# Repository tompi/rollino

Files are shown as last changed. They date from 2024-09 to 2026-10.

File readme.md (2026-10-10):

Rollino
=======

An attempt to make a cheap, solid and low profile DIY finger trackball.

The ball floats just 1 mm above the table on three ceramic support balls.
Two PMW3610 sensors look up at the ball from below its equator, placed so
their lines of sight are orthogonal (X, Y and twist are all observable).
A Seeed XIAO nRF52840 running ZMK and a 602020 LiPo lie flat in a squashed
dome in front of the ball. The XIAO is soldered upside down onto a base PCB
that sits in a groove in the underside and reaches round under both sensors,
each wired up with a short FPC ribbon; a cover over the whole underside hides
it, held by the same screws.

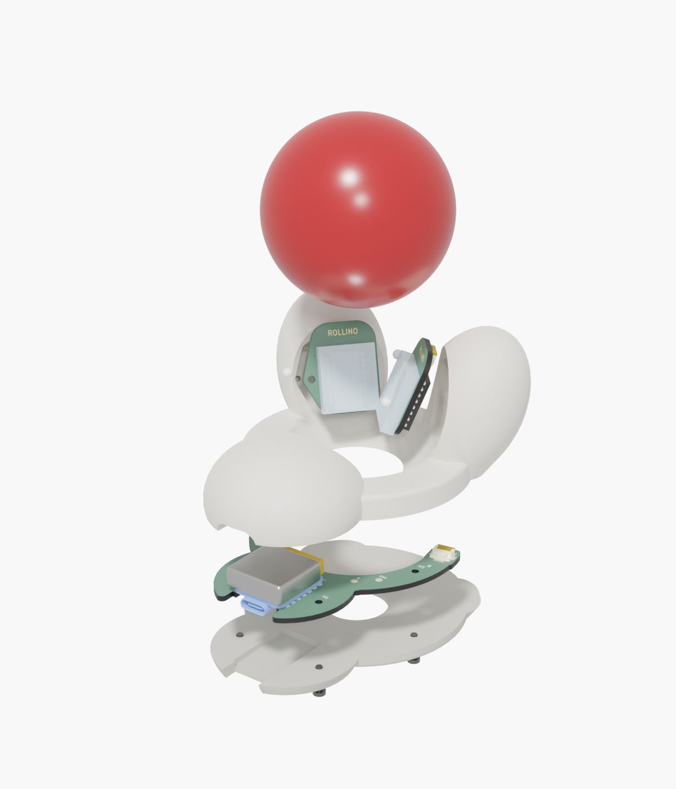
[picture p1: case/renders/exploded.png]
Exploded view


- `case/rollino.scad` - parametric OpenSCAD model (ball size, sensor/MCU
  placement, battery, ...). Set `part` to `assembly`, `exploded`, `hardware`, `section`,
  or `body` / `base_cover` for printable parts.
- `case/renders/` - preview renders: `case/render_previews.sh` (OpenSCAD) and
  `case/render_exploded.sh` (Blender, with KiCad's 3D models of the boards).
- `pcb/` - KiCad projects for the sensor boards and the base board: schematics
  and routed boards, generated from the case model (see [pcb/readme.md](pcb/readme.md)).

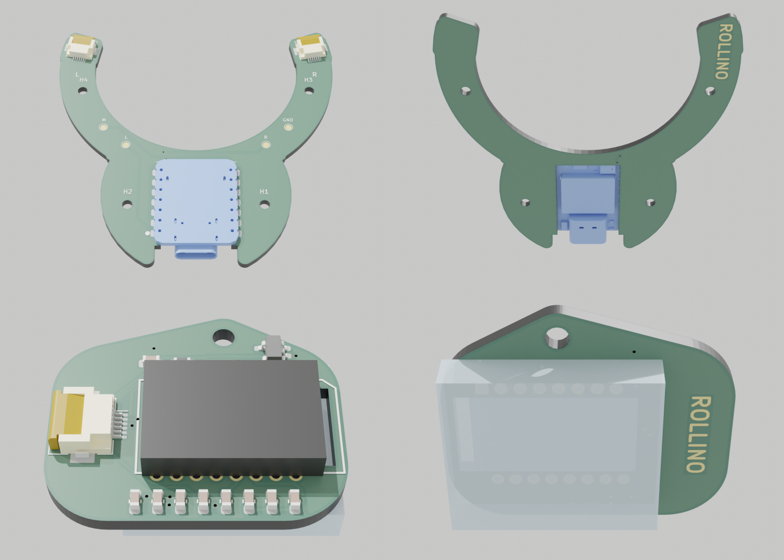
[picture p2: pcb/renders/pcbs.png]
The PCBs, top and bottom

- [parts.md](parts.md) - everything to order for one Rollino.
- `datasheets/` - component datasheets. The PMW3610 datasheet is available
  [here](https://www.epsglobal.com/Media-Library/EPSGlobal/Products/files/pixart/PMW3610DM-SUDU.pdf?ext=.pdf).

Firmware
--------

ZMK, built by GitHub Actions on every push (download `firmware.zip` from the
run, then double-tap the XIAO's reset and copy the `.uf2` onto it). It's a
standalone Bluetooth/USB mouse.

- `zmk/boards/shields/rollino/` - the shield: pins, the two PMW3610 sensors
  (Zephyr's driver), three optional buttons.
- `zmk/src/ball_fusion.c` - combines the two sensors: each one only sees the
  ball's surface sliding past in its own tilted plane; together they give the
  ball's whole rotation. Rolling moves the pointer (as if the finger on top
  dragged it), twisting about the vertical axis scrolls.
- `config/rollino.keymap` - the buttons: left, right, middle click.

| XIAO pin | Use |
|---|-----|
| D8 | SCLK, both sensors |
| D10 | SDIO, both sensors (SPI MOSI and MISO on the same pin) |
| D7 | NCS, right sensor |
| D6 | NCS, left sensor |
| D3 | MOTION, right sensor |
| D2 | MOTION, left sensor |
| D0, D1, D9 | optional buttons to GND: left, right, middle click |
| D4, D5 | free |

**Calibrating the sensors' orientation.** The fusion needs to know which way
each sensor's X axis points (`rotation` in the shield's `ball_fusion` node,
plus the sensor's `invert-x` / `invert-y`), which depends on how the chip
sits on the sensor PCB. Roll the ball right: the pointer should go right;
towards you: down; twist it: scroll, with no drift. If one direction is off,
try one sensor at a time (cover the other's lens) and fix its rotation /
inversion until rolling right moves the pointer mostly right.

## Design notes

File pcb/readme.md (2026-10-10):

Rollino PCBs
============

Two KiCad 8 projects, generated from the case model: board outlines, and
where the XIAO, the FPC connectors and the screw holes go, all come from
`case/rollino.scad`.

Both boards, top and bottom

Rebuild them after changing the case (KiCad's own Python; Freerouting 1.5,
Java, Blender 3.x and ImageMagick for routing and rendering):

```
PY=/Applications/KiCad/KiCad.app/Contents/Frameworks/Python.framework/Versions/Current/bin/python3
$PY pcb/gen/generate.py     # schematics, footprints placed on their nets
$PY pcb/gen/route.py        # Freerouting routes every net, GND poured on both layers
pcb/gen/render_pcbs.sh      # the renders above, the layout images and schematic PDFs
```

They overwrite the projects, so make changes in the scripts rather than the
KiCad files, or stop using them once you start editing the boards by hand.

Both boards are routed (0.2 mm tracks, 0.15 mm clearance, 0.3 mm from the
edges, 0.6/0.3 mm vias) and pass DRC with nothing to report, warnings
included (`kicad-cli pcb drc --schematic-parity --severity-all`); the
schematics pass ERC. The sensor board's references are on its fab layer
only, as are the base board's test points' (their labels name them): the
silkscreen has no room for them.

Sensor board (`sensor/`, two needed)
--------------------------------------

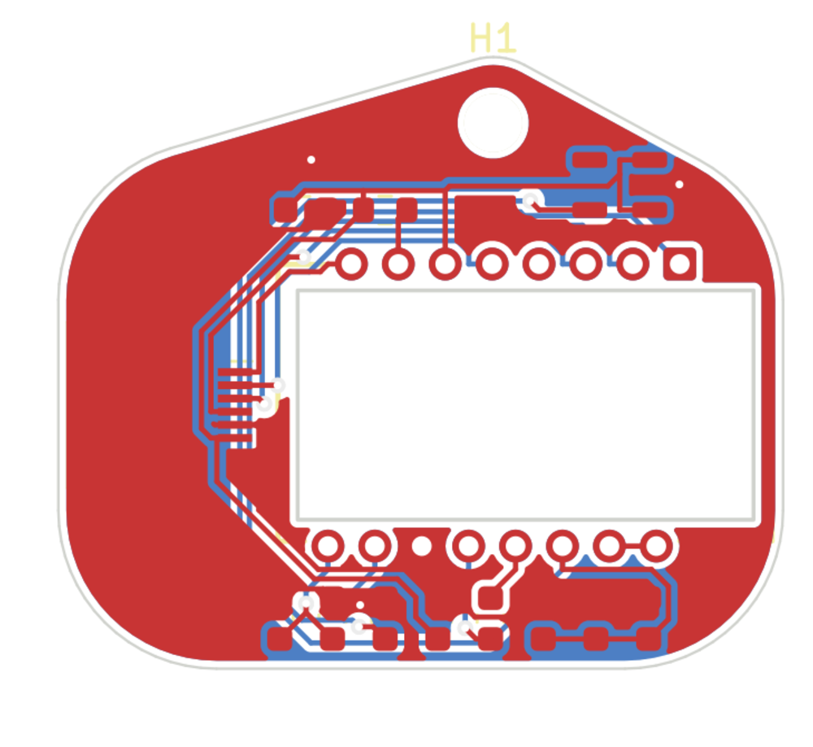
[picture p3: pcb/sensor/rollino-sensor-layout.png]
Sensor board


[Schematic (PDF)](sensor/rollino-sensor-schematic.pdf)

The same board for both sensors. It's screwed into its pod from the ball
side, chip side out, lens towards the ball; the case's pocket matches its
outline, ear included.

- PMW3610DM-SUDU + LM18-LSI lens: circuit and footprint (with the lens cutout)
  after [badjeff/pmw3610-pcb](https://github.com/badjeff/pmw3610-pcb)
  (CERN-OHL-P-2.0)
- TPS7A0518 1.8 V LDO for the sensor's core: 1 uA quiescent, instead of the
  ~34 uA of the TLV74318 used there, which would otherwise draw more than the
  resting sensor
- FH12-6S-0.5SH FPC connector at the board's up-slope end, mouth facing off
  the edge, so the ribbon is easy to push in and latch before the board goes
  into its pod; the ribbon then bends back over the connector and runs over
  the chip's back to the base board (the pod has room for the bend)
- the ribbon's way down through the pod is roomy (5.5 mm wide, the case
  checks it with a 1.5 mm thick stand-in: `part="fpc_check"` must be empty),
  so its free end can be fed through from the pod or from underneath before
  the boards go in
- the regulator's EN is tied to its VIN by a fixed track between its rows of
  pins (route.py keeps it): the board edge leaves no other way in
- a small ROLLINO logo in bare copper on the back, between the edge and the
  lens
- board frame: origin on the optical axis, x down the slope (towards the
  table), y sideways; nothing goes behind the ear (y beyond -7.9 mm, x
  -6.9..-0.9), where the case has the screw boss

Base board (`base/`)
--------------------

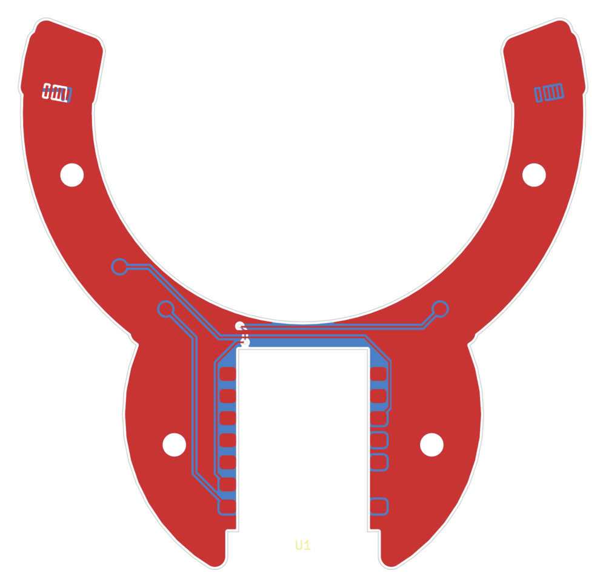
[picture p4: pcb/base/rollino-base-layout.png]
Base board


[Schematic (PDF)](base/rollino-base-schematic.pdf)

Lies in a groove in the case's underside, held (with the cover under it) by
four M2 screws.

- Seeed XIAO nRF52840 soldered **upside down** by its castellated edges: its
  parts (USB-C included) hang through the cutout into a pocket in the cover;
  its battery pads face up, and the LiPo's leads solder straight onto them
- J1 (right sensor) and J2 (left) at the band's ends, along it, mouths facing
  the ribbons coming along the channel in the case's underside
- TP1-TP3: optional buttons (left, middle, right click) to TP4 (GND)
- the ROLLINO logo is bare copper (no solder mask) on the back of the band
- pins as in the firmware (`zmk/boards/shields/rollino/rollino.overlay`)

Ribbons
-------

Two 6-way 0.5 mm FFCs, 50 mm long (the stock length: 40 mm ones are hard
to find), with opposite-side (type B) contacts. Each comes down from its
sensor pod under the band's old end, turns in, and with one crease (about
45 degrees, folded flat) lies along a channel in the case's underside,
straight into the base board's connector at the end of the band; the case
model sets where that is from the cable's length (`fpc_len`). The crease
turns the ribbon over, hence type B. The pins at each end are numbered from
the ribbon's path so that each signal meets itself: put the ribbon in, fold
it at the crease and lay it in its channel before the base board goes up.

Parts
-----

| Board | Ref | Part |
|---|-----|---|
| sensor (x2) | U1 | PMW3610DM-SUDU + LM18-LSI lens |
| | U2 | TPS7A0518PDBVR (SOT-23-5) |
| | J1 | Hirose FH12-6S-0.5SH (or JUSHUO AFC01-S06FCA) |
| | R1 | 10k 0603 |
| | C1 | 3.3 uF 0603 |
| | C2, C3 | 100 nF 0603 |
| | C4 | 100 nF X7R 0603 |
| | C5 | 10 nF 0603 |
| | C6 | 10 uF X7R 0603 |
| | C7 | 10 nF X7R 0603 |
| | C8, C9 | 1 uF 0603 |
| base | U1 | Seeed XIAO nRF52840 (not Sense) |
| | J1, J2 | Hirose FH12-6S-0.5SH (or JUSHUO AFC01-S06FCA) |

`lib/` has the project's own symbols, footprints and 3D models (the XIAO's
from Seeed's, the PMW3610 and its lens as plain blocks); everything else is
from KiCad's standard libraries.

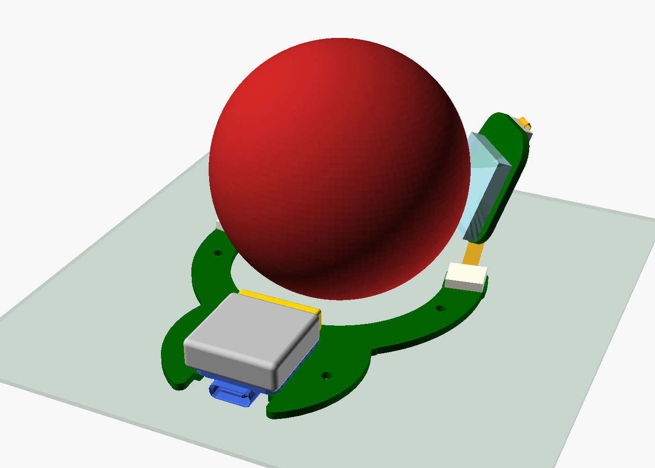
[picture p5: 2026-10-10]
case/renders/hardware_front.png

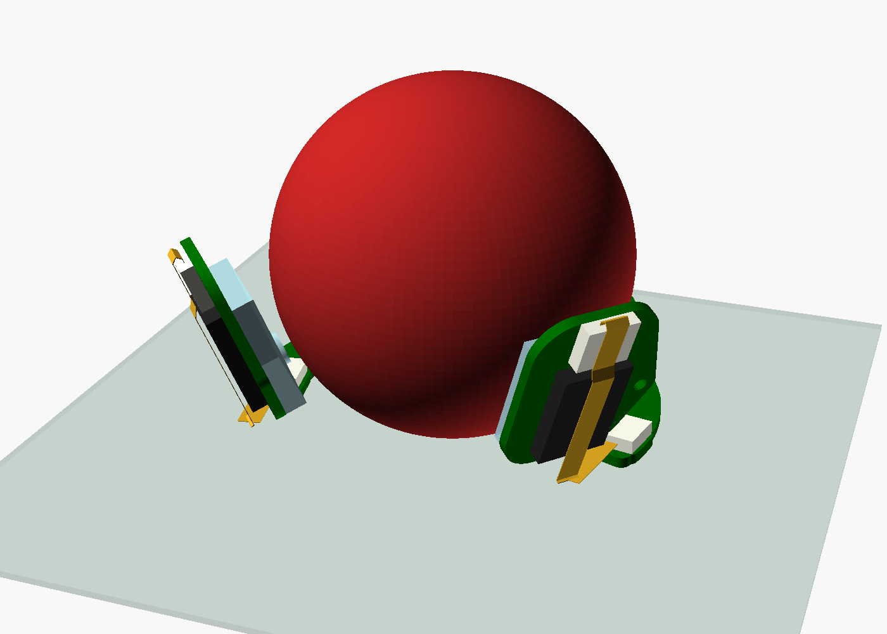
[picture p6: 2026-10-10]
case/renders/hardware_back.png

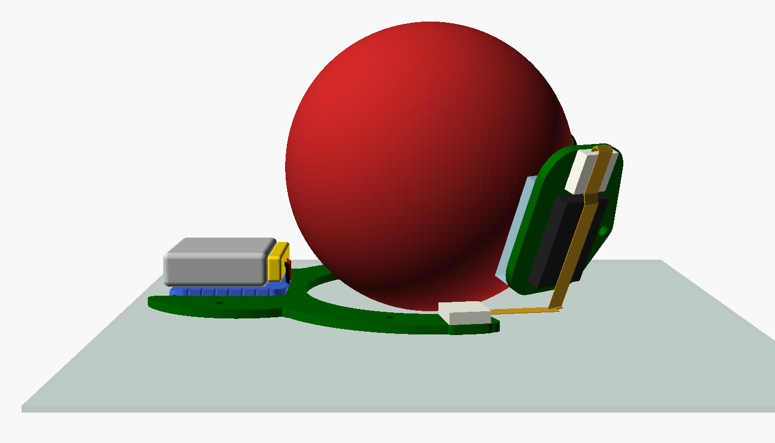
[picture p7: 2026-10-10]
case/renders/hardware_side.png

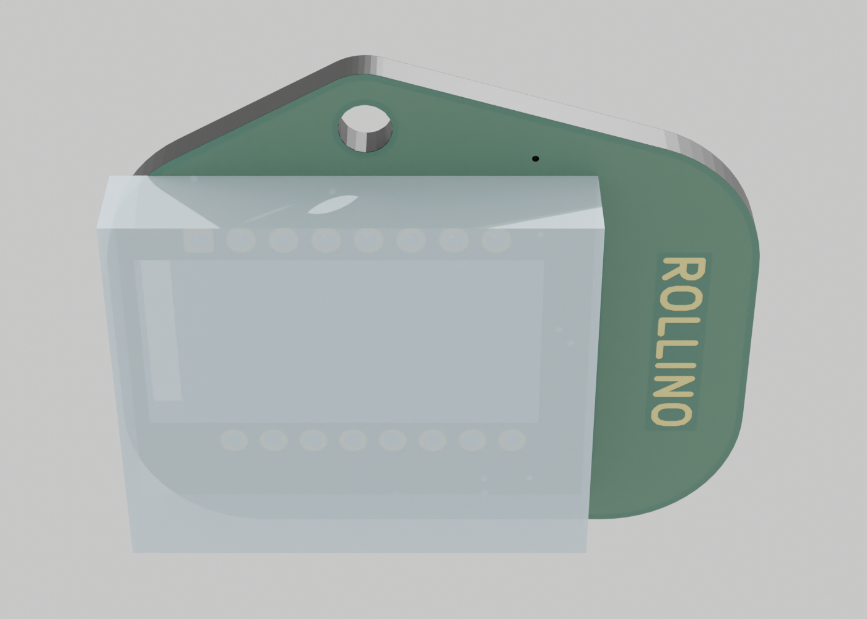
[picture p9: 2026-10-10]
pcb/renders/sensor-bottom.png

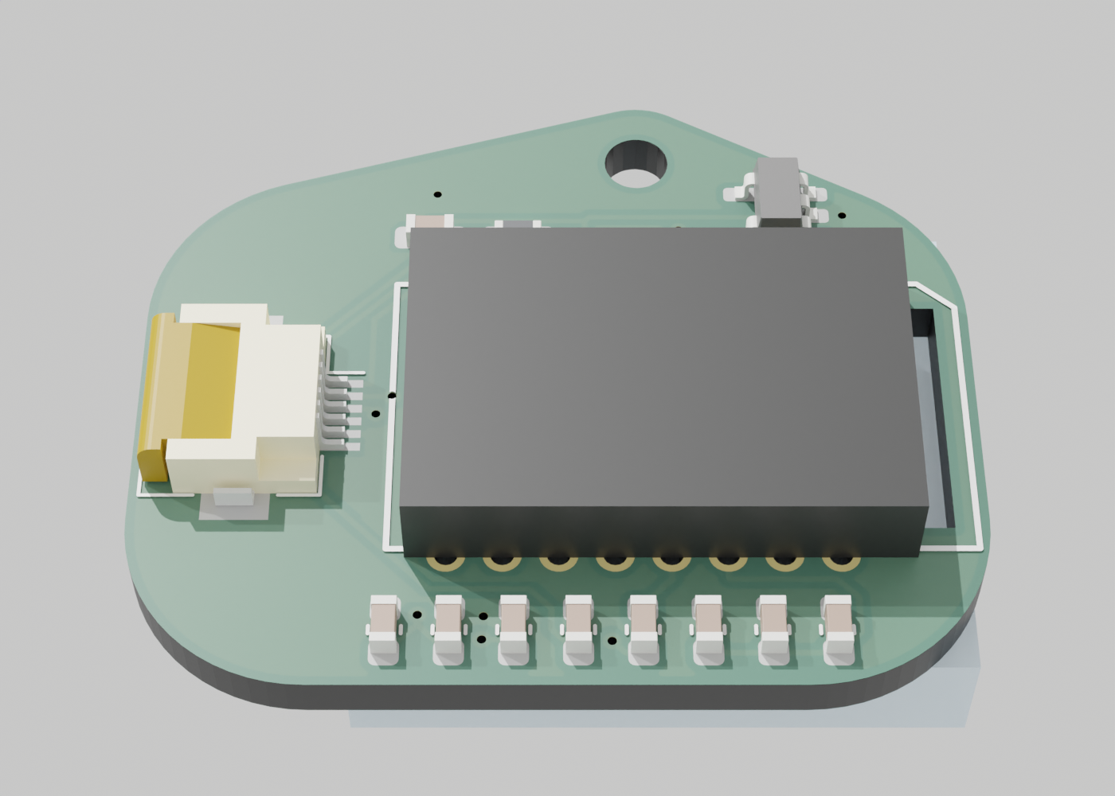
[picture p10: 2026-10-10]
pcb/renders/sensor-top.png

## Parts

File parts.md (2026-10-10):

Parts list
==========

Everything for one Rollino; quantities are totals (it has two sensor boards).
The case itself (`body` and `base_cover` in `case/rollino.scad`) is printed.

PCBs
----

| Qty | Board | Notes |
|-----|---|---|
| 2 | sensor board (`pcb/sensor/`) | 2 layers, 1.6 mm FR4; has a cutout for the lens |
| 1 | base board (`pcb/base/`) | 2 layers, 1.6 mm FR4; has a cutout for the XIAO's parts |

0.2 mm tracks, 0.15 mm clearance, 0.3 mm drills: any fab's standard process.
Both have a bare-copper logo, so pick ENIG (or HASL) rather than bare copper
finish.

Electronics
-----------

| Qty | Part | Where | Notes |
|-----|---|---|---|
| 1 | Seeed XIAO nRF52840 (not Sense) | base U1 | soldered upside down by its edge pads |
| 2 | PixArt PMW3610DM-SUDU | sensor U1 | |
| 2 | LM18-LSI lens | under each PMW3610 | the PMW3610's lens; often sold with it |
| 2 | TI TPS7A0518PDBVR (1.8 V LDO, SOT-23-5) | sensor U2 | |
| 4 | Hirose FH12-6S-0.5SH(55) (or JUSHUO AFC01-S06FCA) | sensor J1, base J1/J2 | 6-pin, 0.5 mm FPC connector |
| 2 | 6-way FFC, 0.5 mm pitch, 50 mm, **opposite-side (type B) contacts** | sensor to base | for 0.3 mm thick FPC connectors (FH12); 50 mm is the stock length |
| 1 | LiPo 602020, about 200 mAh, with protection board | on the XIAO's back | up to 22 x 20 x 6.5 mm; leads solder to the XIAO's battery pads |

Passives, all 0603, for both sensor boards together (10 V or more):

| Qty | Value | Where (on each sensor board) |
|-----|---|---|
| 6 | 100 nF X7R | C2, C3, C4 |
| 4 | 10 nF X7R | C5, C7 |
| 4 | 1 uF | C8, C9 |
| 2 | 3.3 uF | C1 |
| 2 | 10 uF X7R | C6 |
| 2 | 10 k resistor | R1 |

Optional: up to three momentary switches for left, middle and right click,
wired from the base board's TP1-TP3 pads to TP4 (GND).

Mechanical
----------

| Qty | Part | Notes |
|-----|---|---|
| 1 | 55 mm trackball ball | the size Kensington's trackballs use (Expert Mouse, SlimBlade), sold as replacements |
| 3 | 3 mm ceramic bearing balls (ZrO2 or Si3N4) | the ball's supports; get a few spares |
| 4 | M2 x 8 countersunk thread-forming screws for plastic | through the cover and base board into the case |
| 2 | M2 x 6 thread-forming screws for plastic, low (pan or wafer) head | one through each sensor board's ear |

Screw lengths are from the model: the cover and base board are 5.2 mm
together, with 4.5 mm pilot holes above them; each sensor board is 1.6 mm,
with a 5 mm pilot hole behind it.

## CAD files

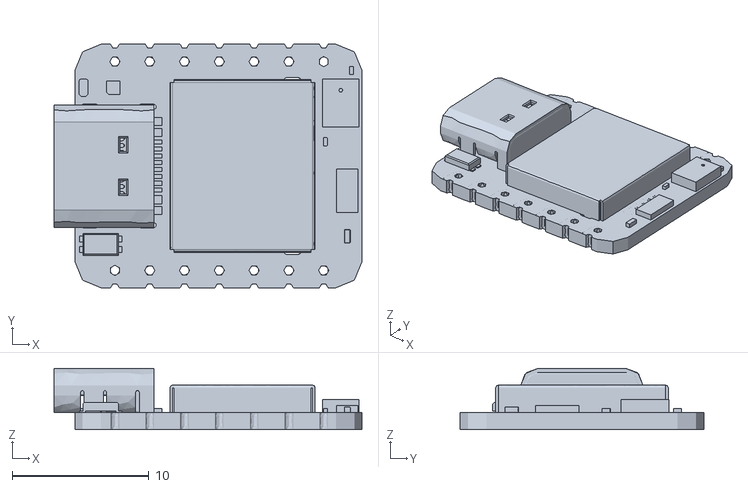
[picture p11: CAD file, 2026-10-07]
pcb/3d/xiao-nrf52840.stl
22.5 x 17.8 x 4.46

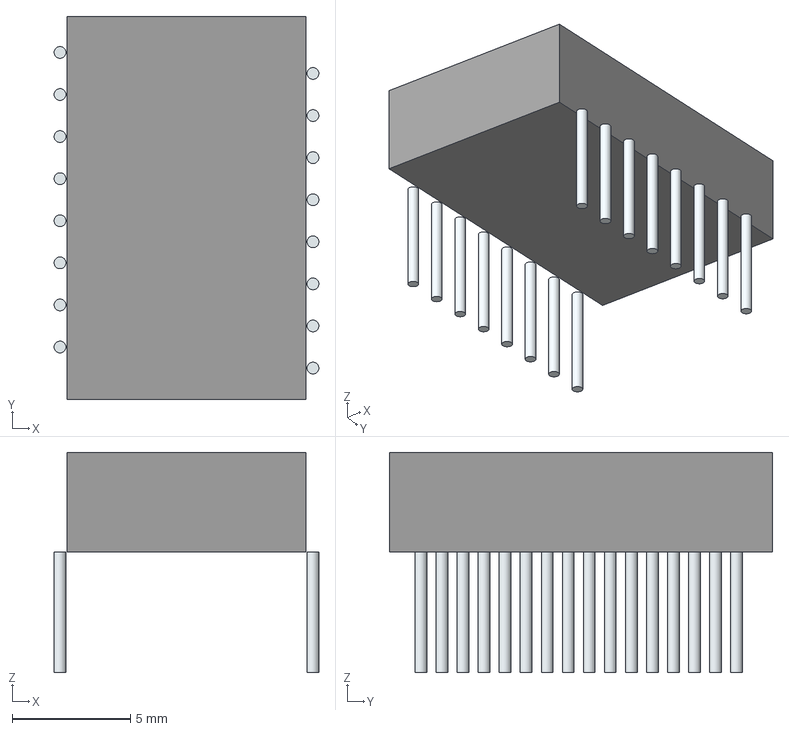
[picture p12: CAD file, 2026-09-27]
pcb/3d/pmw_3389-T3QU.stp
11.2 x 16.2 x 9.31 mm
Leads

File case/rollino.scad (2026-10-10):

// Rollino - low-profile finger trackball
//
// Ball floats `ball_gap` above the table on three ceramic support balls.
// Two PMW3610 sensors sit in pods at the back-left/back-right, looking up at
// the ball from as low as they fit; their azimuths are chosen so the lines of sight are
// ~90 deg apart, so X, Y and twist are all observable.
// A XIAO nRF52840 + LiPo lie flat in a squashed-sphere pod at the front,
// USB-C pointing forward, pushed in against the ball. The XIAO is soldered
// to a base PCB that sits in a groove in the case's underside; it reaches
// round under each sensor, where a short FPC ribbon runs up to the sensor
// board. A cover over the whole underside hides it, and the same screws hold
// both.
//
// Coordinates: table is z=0, front (towards the user) is -y.
// Azimuths are measured from the front, positive towards +x.

/* [View] */
// assembly | exploded | section | hardware | body | base_cover |
// base_pcb / sensor_pcb (2D board outlines, for ../pcb/gen/generate.py)
part = "body";
// azimuth of the vertical cut plane for part="section"
section_az = 135;
// part="exploded" draws only this piece of it, if set (body, ball,
// supports, sensor_boards, electronics, base_pcb, cover, screws, or the
// battery's pouch, pcm and leads): ../case/render_exploded.sh renders it in
// Blender a piece at a time, with KiCad's models of the boards
explode_only = "";

/* [Ball] */
ball_d = 55;
// ball bottom above table
ball_gap = 1;
// radial gap between ball and case
ball_clear = 1;

/* [Ball supports] */
// ZrO2 / Si3N4 bearing balls
support_d = 3;
// angle from the ball's bottom pole
support_polar = 45;
// kept clear of the front pod, which covers azimuth 0 low down
support_az = [180, 60, -60];

/* [Rim] */
rim_h = 11;
// rim outer radius = ball radius + rim_wall
rim_wall = 7;
bottom_hole_r = 10;
wall = 1.6;

/* [Organic shaping] */
// corner radius of the round sensor PCBs
pcb_r = 6;
// rounding of the rim patches that blend a pod into the rim
shell_r = 4;
// how far a pod's ellipsoid is inflated past its zones' combined bounding
// box (x, y, z), so it still fully covers their corners
bump_k = [1.45, 1.45, 2.0];
// same, for the two (smaller) sensor pods; z is pushed further so they read
// as thick, ball-like bumps rather than flattened domes
sensor_k = [1.45, 1.45, 2.3];

/* [Sensors: PMW3610 + LM18-LSI] */
// true: put the sensors as low as floor_z allows
sensor_el_auto = true;
// elevation above the ball's equator (if not auto)
sensor_el = -23;
// true: choose azimuths that make the two lines of sight orthogonal
sensor_az_auto = true;
sensor_az = [130, -130];
// package centre sits this far up-slope of the optical axis (datasheet fig. 5: 7.09 - 3.18)
sensor_optical_offset = 3.9;
// datasheet: lens reference plane to surface, 2.4 +-0.2
lens_ref_z = 2.4;
// ASSUMED (same stack as PixArt LM19 designs) - verify against LM18 drawing
pcb_top_z = 7.4;
pcb_t = 1.6;
// along the slope (up/down)
pcb_w = 22;
// tangential (horizontal)
pcb_h = 20;
lens_w = 20;
lens_h = 17;
// chip + components above the sensor PCB
parts_h = 3;
// the PCB has a screw ear on one of the lens' long sides; it goes in from
// the ball side and one M2 self-tapping (plastite) screw through the ear
// holds it against the back of its pocket; pilot hole diameter
pcb_screw_d = 1.8;
// hole centre, beside the optical axis (tangential)
pcb_screw_y = lens_h / 2 + 2.2;
// pilot hole depth behind the PCB's back face
pcb_screw_depth = 5;
pcb_ear_d = 5;
// which side the ear is on: 1 = towards increasing azimuth, -1 = decreasing;
// the same on both sensors, so they're the same board
pcb_screw_side = 1;
// FPC connector, 6-pin 0.5 mm (Hirose FH12-6S-0.5SH, or a clone such as
// JUSHUO AFC01-S06FCA): [length, depth with its solder tails, height]. It
// sits on the sensor board's back beyond the chip's up-slope end, mouth
// facing off the board's up-slope edge, where the ribbon (6 x 0.5 mm FFC,
// fpc_w wide) is easy to push in and latch before the board goes in; it
// then bends back over the connector, runs down over the chip's back, past
// the board's low end and down to the base PCB, which has the same
// connector under each sensor
fpc_conn = [8.1, 7.1, 2.1];
fpc_w = 3.5;
// room past the board's up-slope edge for the ribbon's U-turn
fpc_bend = 2.6;
// the ribbon's channel down to the base PCB, roomy enough to feed its end
// through from either end before the boards go in: [width, depth over the
// chip]; the case checks the room with a ribbon this much thicker (and
// 1 mm wider) than it is: part="fpc_check" must come out empty
fpc_chan = [fpc_w + 2, 1.6];
fpc_clear = 1.5;
// the sensor board reaches this much further up the slope than the
// symmetric pcb_w, for that connector (up there it doesn't push the sensors
// up the ball, as a longer low end would)
pcb_ext = max(0, (16.2 + 0.6) / 2 + 1 + fpc_conn.y - pcb_w / 2);

/* [Electronics pod] */
// LiPo cell 602020 (~200 mAh): [length, width, thickness]
// sizes vary between makers; this is the larger end (22 x 19.5 x 6.5 is
// listed), length including the protection board folded over one end
batt = [22, 20, 6.5];
// length of that protection-board end (kapton-taped), towards the ball
batt_pcm = 2.5;
// room behind it for the leads, which fold down to the XIAO's pads
batt_leads = 1.2;
// Seeed XIAO nRF52840 (not Sense): [length, width, PCB thickness]; sizes
// below are from Seeed's 3D model (../pcb/3d/xiao-nrf52840.stl, converted
// from the Sense STEP at https://files.seeedstudio.com/wiki/XIAO-BLE/seeed-studio-xiao-nrf52840-3d-model.zip;
// same board, plus an IMU and a mic)
xiao = [21, 17.8, 1];
// height of the USB-C receptacle (the tallest part, 3.2) on the XIAO's
// component side, and how far it overhangs the board edge
xiao_parts_h = 3.3;
usb_overhang = 1.55;
// pads on the XIAO's underside, and the gap between them and the cell
xiao_pads = 0.25;
batt_gap = 0.5;
// cavity: the XIAO is soldered upside down onto the base PCB by its
// castellated edges, its parts (USB-C included) hanging down through a
// cutout in the PCB into a pocket in the cover; the battery lies on its
// back, right on the battery pads; x runs from the USB end towards the ball
elec_size = [max(xiao.x + usb_overhang, batt.x + batt_leads) + 0.6, max(xiao.y, batt.y) + 0.6,
             xiao.z + xiao_pads + batt_gap + batt.z + 0.3];
// the PCB cutout under the XIAO leaves its castellated pads this much to sit on
xiao_pad_w = 1.5;
// the pod's outer is a squashed sphere this wide (seen from above), as low
// as it can be while covering the cavity
elec_dome_d = 46;
// how far the dome's centre sits behind the cavity's, towards the ball, so
// less of it sticks out in front (the cavity itself stays put)
elec_dome_back = 3.5;
// base PCB screws either side of the cavity, from its centre line
elec_screw_y = max(xiao.y, batt.y) / 2 + 4.8;
// plug overmold recess in front of the receptacle: [width, height]
usb_plug = [13.5, 7.5];
// lowest point of any pod above the table
floor_z = 0;

/* [Base PCB + cover] */
// the cover is the bottom slab of the case, screwed on; the PCB lies on it,
// in a groove in the case above, and countersunk M2 screws go up through
// both into the case. The upside-down XIAO's USB-C is centred on the cover's
// top, so this is what lifts a plug (overmold up to ~6.5 tall) off the table
base_cover_t = 3.6;
base_pcb_t = 1.6;
// band round the ball's bottom hole, from under the front pod to under
// each sensor: [inner, outer] radius; inside it the ball's cup and the
// support balls' holes come down close, outside it the rim's foot is rounded
base_band_r = [24, 32.5];
// the ribbons are stock fpc_len FFCs (40 mm ones are hard to get): each
// comes down from its sensor pod under the band's old end, turns in, and
// with a 45-ish degree crease lies flat along a channel in the case's
// underside (the cover holds it), straight into an FPC connector that faces
// it at the end of the band; the band ends there, its length set by what
// the ribbon needs, less fpc_slack for leeway. Pocket over the connector
// (the ribbon goes in before the board goes up into the case, so it only
// needs room for the closed connector): [beyond the mouth, height]
fpc_len = 50;
fpc_slack = 1.5;
fpc_pocket = [0.5, fpc_conn.z + 0.8];
// extra screws on the band: [azimuth, radius] (plus two under the front
// pod), and the pilot holes' depth above the PCB (the rim is only rim_h tall)
base_screws_polar = [[75, 27.5], [-75, 27.5]];
base_screw_depth = 4.5;

$fn = 64;

R = ball_d / 2;
zc = ball_gap + R;
eps = 0.01;

// ---------- frames ----------

// Local frame on the ball surface: z = outward normal (0 at ball surface),
// y = horizontal tangent, x = tangent pointing down the slope.
module at_ball(az, el) {
  translate([0, 0, zc]) rotate([0, 0, az - 90]) rotate([0, 90 - el, 0])
    translate([0, 0, R]) children();
}
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

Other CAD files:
pcb/3d/pmw_3389-T3QU.stl

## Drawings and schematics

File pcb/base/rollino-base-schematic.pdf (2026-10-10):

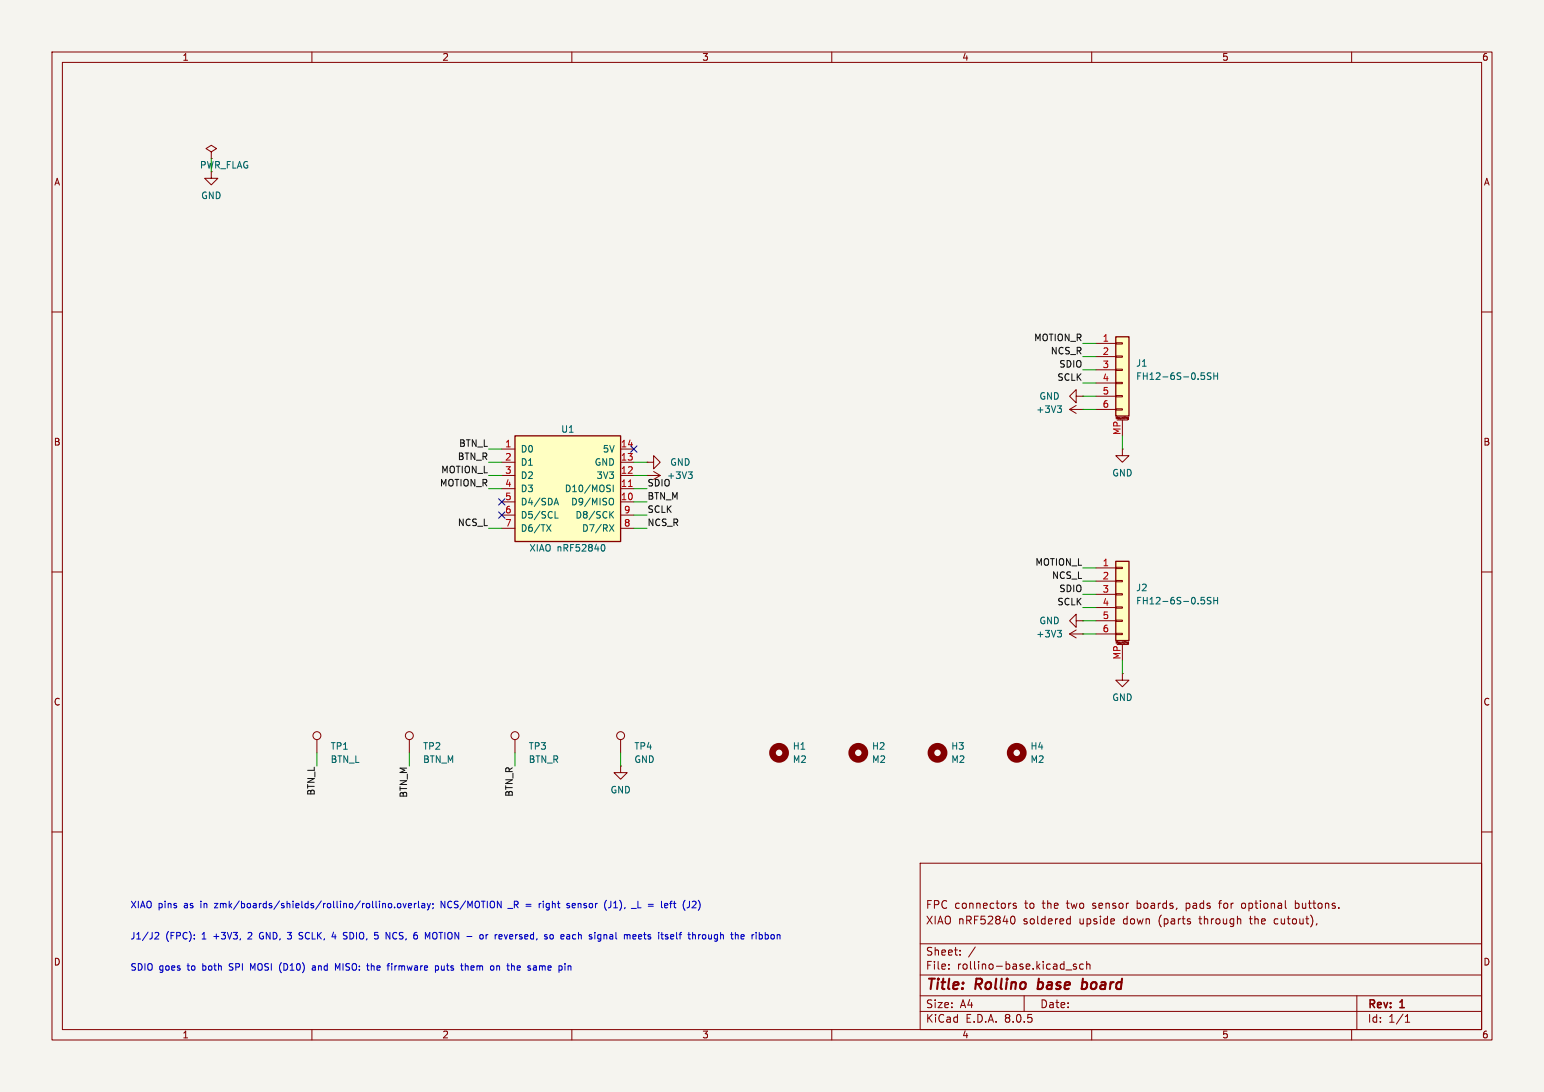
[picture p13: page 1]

Id: 1/1 Title: Rollino base board

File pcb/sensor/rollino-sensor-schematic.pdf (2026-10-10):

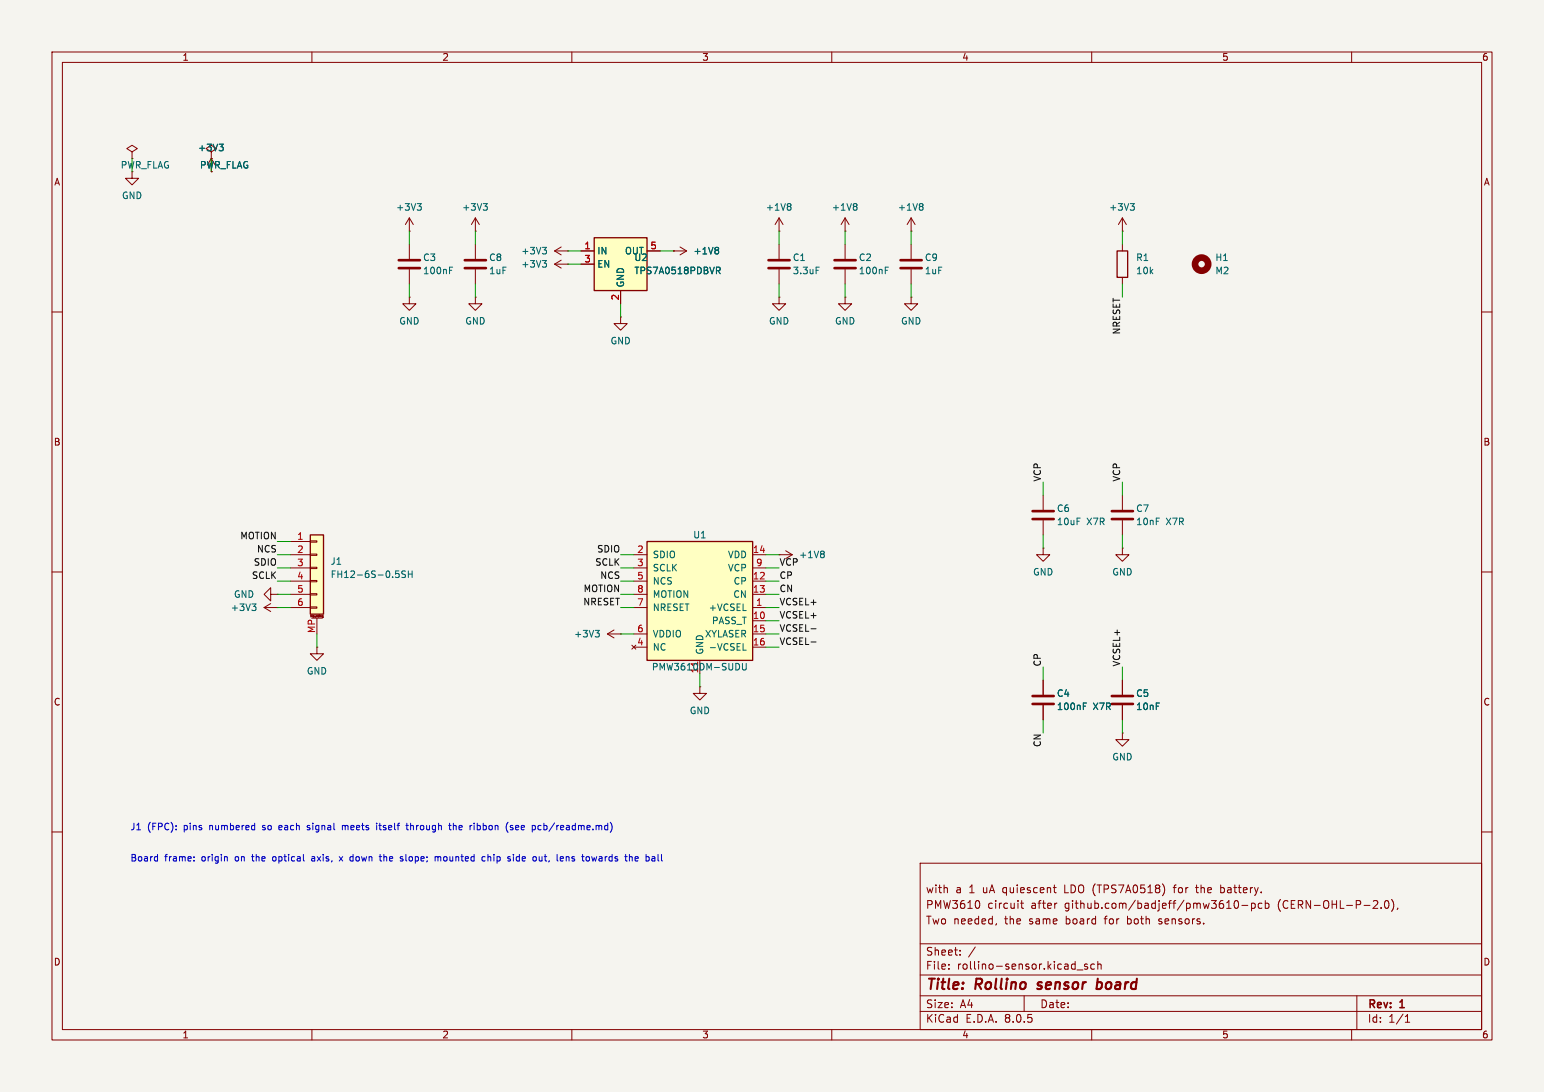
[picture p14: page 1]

Id: 1/1 Title: Rollino sensor board

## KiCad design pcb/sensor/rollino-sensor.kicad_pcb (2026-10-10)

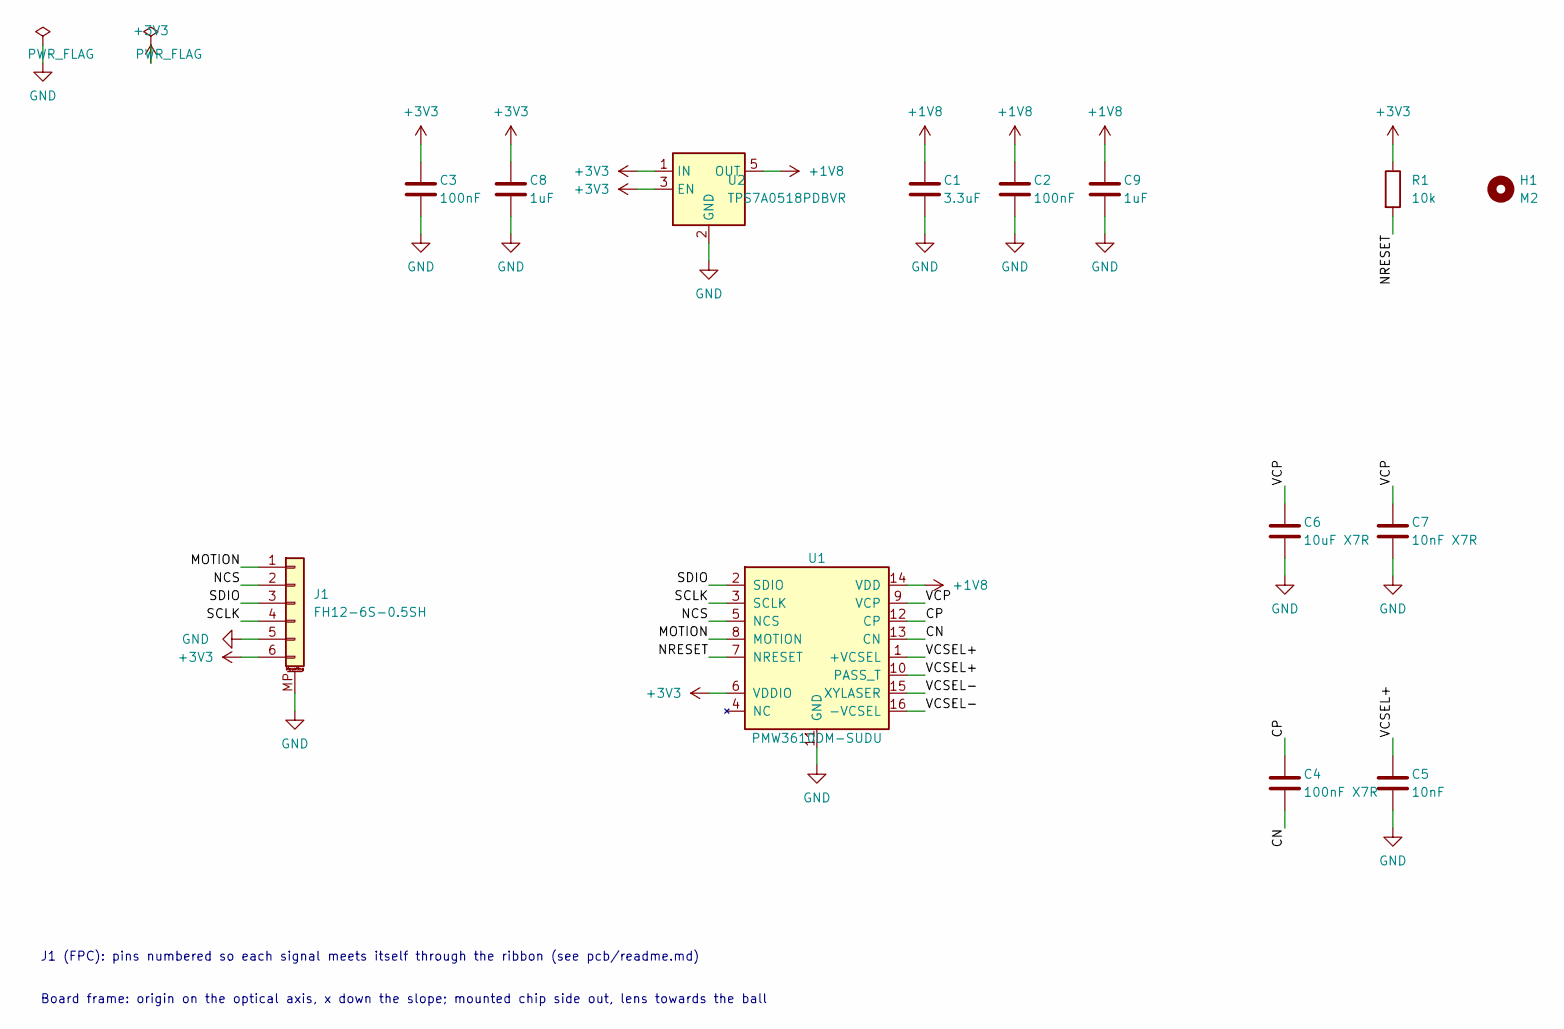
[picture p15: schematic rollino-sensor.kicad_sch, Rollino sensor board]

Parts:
C1: 3.3uF; C_0603_1608Metric
C2, C3: 100nF; C_0603_1608Metric
C4: 100nF X7R; C_0603_1608Metric
C5: 10nF; C_0603_1608Metric
C6: 10uF X7R; C_0603_1608Metric
C7: 10nF X7R; C_0603_1608Metric
C8, C9: 1uF; C_0603_1608Metric
H1: M2; MountingHole_2.2mm_M2
J1: FH12-6S-0.5SH; Hirose_FH12-6S-0.5SH_1x06-1MP_P0.50mm_Horizontal
R1: 10k; R_0603_1608Metric
U1: PMW3610DM-SUDU
U2: TPS7A0518PDBVR; SOT-23-5

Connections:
+1V8: C1.1, C2.1, C9.1, U1.14 (VDD), U2.5 (OUT)
+3V3: C3.1, C8.1, J1.6, R1.1, U1.6 (VDDIO), U2.1 (IN), U2.3 (EN)
/CN: C4.2, U1.13 (CN)
/CP: C4.1, U1.12 (CP)
/MOTION: J1.1, U1.8 (MOTION)
/NCS: J1.2, U1.5 (NCS)
/NRESET: R1.2, U1.7 (NRESET)
/SCLK: J1.4, U1.3 (SCLK)
/SDIO: J1.3, U1.2 (SDIO)
/VCP: C6.1, C7.1, U1.9 (VCP)
/VCSEL+: C5.1, U1.1 (+VCSEL), U1.10 (PASS_T)
/VCSEL-: U1.15 (XYLASER), U1.16 (-VCSEL)
GND: C1.2, C2.2, C3.2, C5.2, C6.2, C7.2, C8.2, C9.2, J1.5, J1.MP (MountPin), U1.11 (GND), U2.2 (GND)

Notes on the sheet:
J1 (FPC): pins numbered so each signal meets itself through the ribbon (see pcb/readme.md)
Board frame: origin on the optical axis, x down the slope; mounted chip side out, lens towards the ball

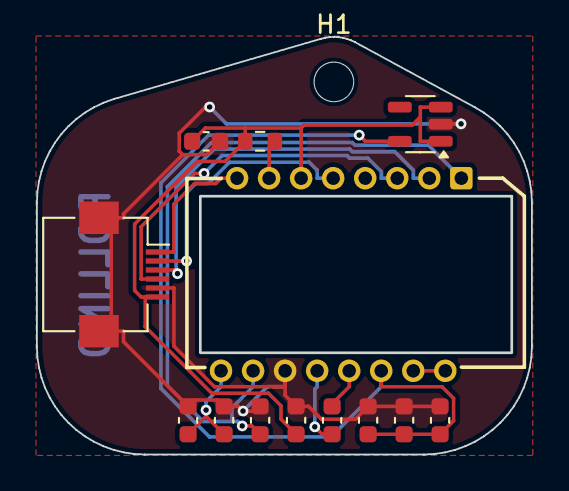
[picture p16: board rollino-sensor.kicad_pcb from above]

Board: 2 copper layers, 27.5 x 23.2 mm, 14 parts (0 on the bottom side), 13 nets.

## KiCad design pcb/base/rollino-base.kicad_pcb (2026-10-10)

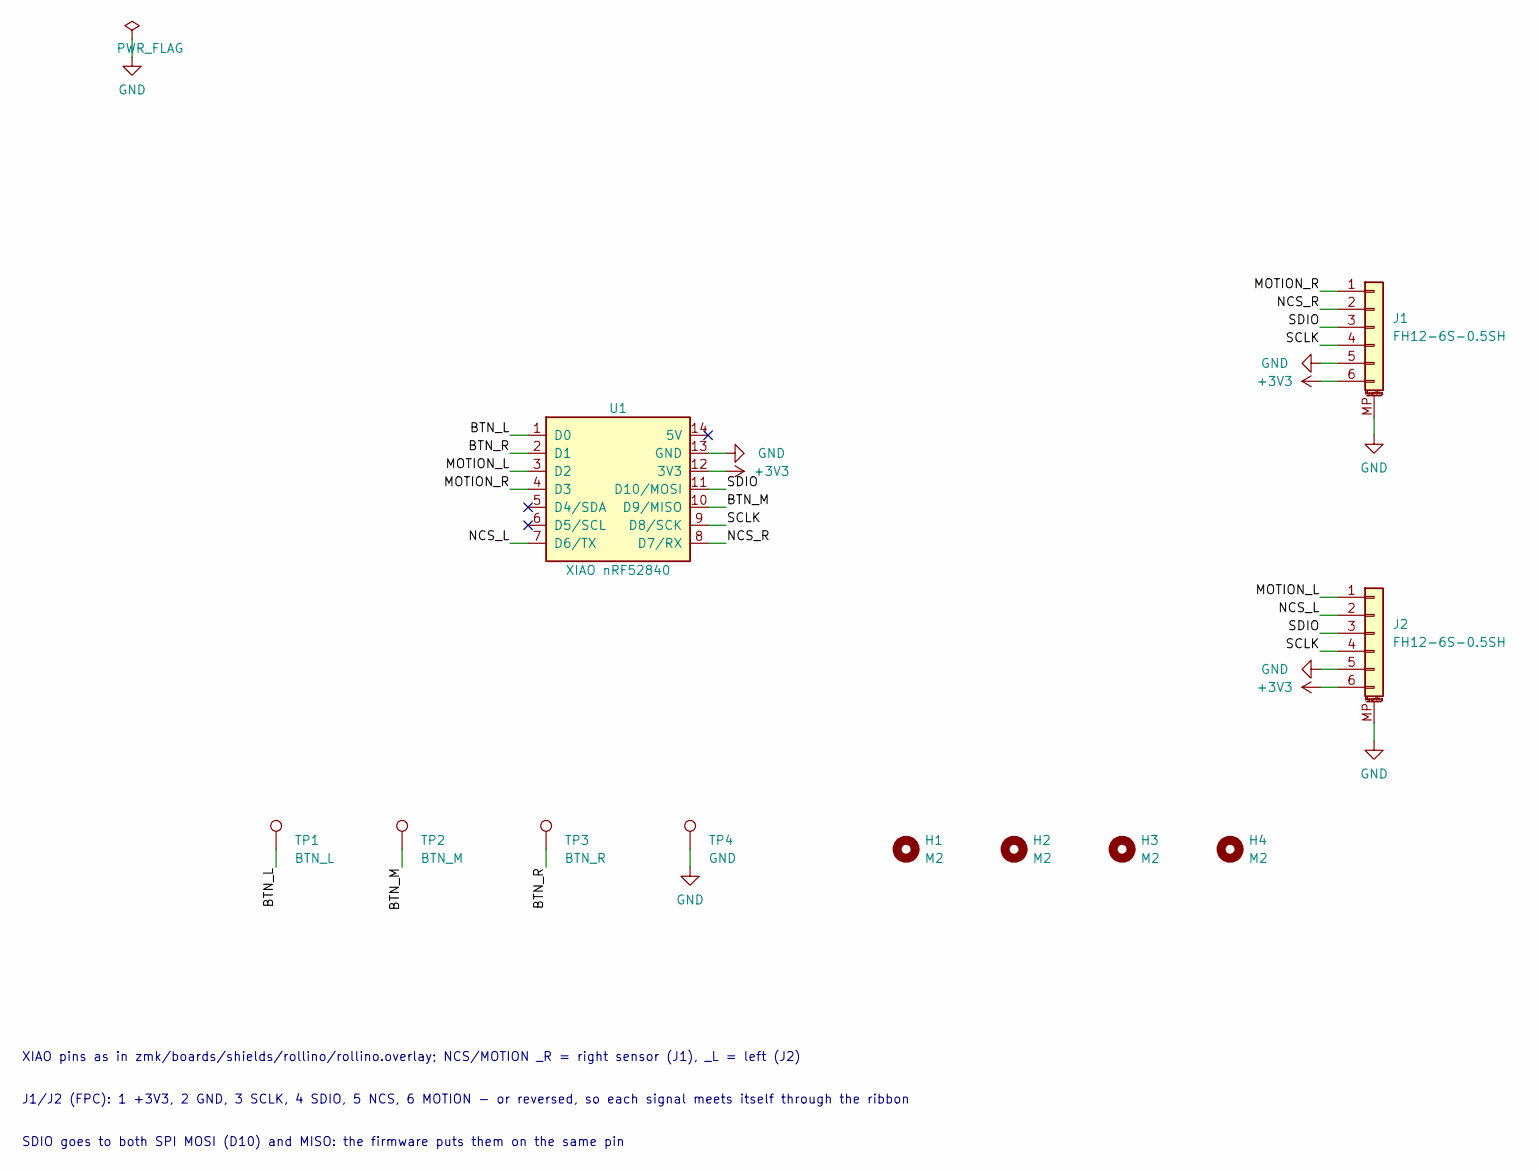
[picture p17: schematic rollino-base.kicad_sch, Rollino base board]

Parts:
H1, H2, H3, H4: M2; MountingHole_2.2mm_M2
J1, J2: FH12-6S-0.5SH; Hirose_FH12-6S-0.5SH_1x06-1MP_P0.50mm_Horizontal
TP1: BTN_L; TestPoint_Pad_D1.5mm
TP2: BTN_M; TestPoint_Pad_D1.5mm
TP3: BTN_R; TestPoint_Pad_D1.5mm
TP4: GND; TestPoint_Pad_D1.5mm
U1: XIAO nRF52840; XIAO_nRF52840_upside_down

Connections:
+3V3: J1.6, J2.6, U1.12 (3V3)
/BTN_L: TP1.1, U1.1 (D0)
/BTN_M: TP2.1, U1.10 (D9/MISO)
/BTN_R: TP3.1, U1.2 (D1)
/MOTION_L: J2.1, U1.3 (D2)
/MOTION_R: J1.1, U1.4 (D3)
/NCS_L: J2.2, U1.7 (D6/TX)
/NCS_R: J1.2, U1.8 (D7/RX)
/SCLK: J1.4, J2.4, U1.9 (D8/SCK)
/SDIO: J1.3, J2.3, U1.11 (D10/MOSI)
GND: J1.5, J1.MP (MountPin), J2.5, J2.MP (MountPin), TP4.1, U1.13 (GND)

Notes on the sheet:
XIAO pins as in zmk/boards/shields/rollino/rollino.overlay; NCS/MOTION _R = right sensor (J1), _L = left (J2)
J1/J2 (FPC): 1 +3V3, 2 GND, 3 SCLK, 4 SDIO, 5 NCS, 6 MOTION - or reversed, so each signal meets itself through the ribbon
SDIO goes to both SPI MOSI (D10) and MISO: the firmware puts them on the same pin

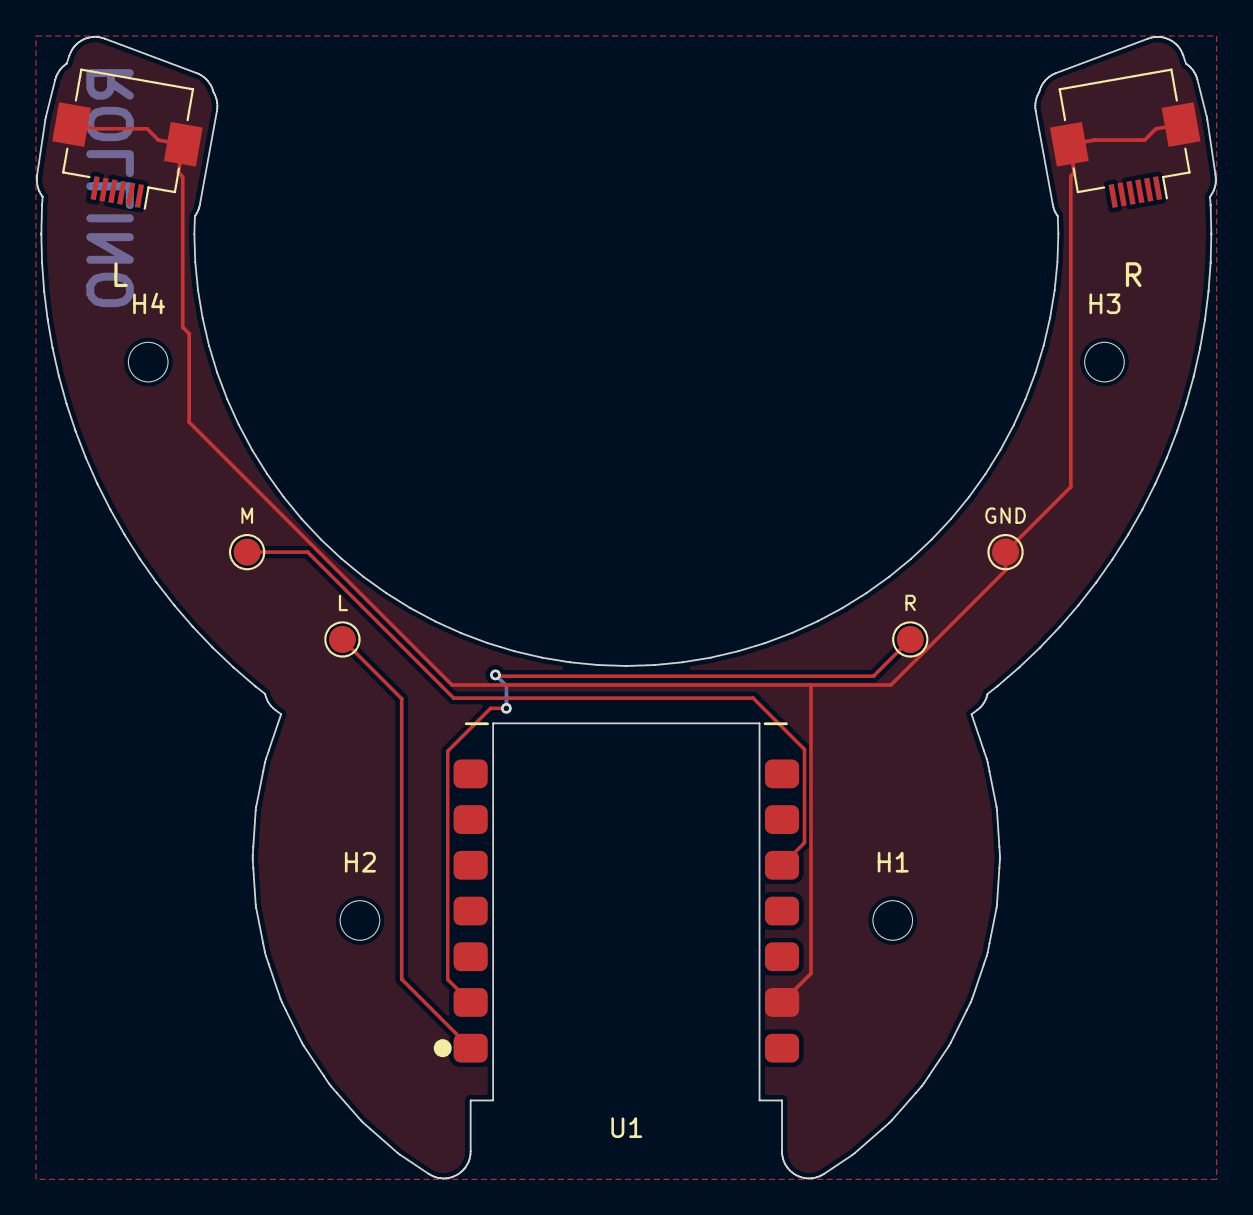
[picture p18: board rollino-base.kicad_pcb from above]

Board: 2 copper layers, 65.5 x 63.4 mm, 11 parts (0 on the bottom side), 11 nets.

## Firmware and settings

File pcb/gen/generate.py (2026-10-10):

#!/usr/bin/env python3
"""Generates the Rollino's KiCad projects: the sensor board (two of them, the
same board) and the base board, each with its schematic.

Board outlines and the positions of everything the case cares about (the
XIAO, the FPC connectors, the screws) come from the case model, so run this
again after changing case/rollino.scad. The boards come out placed but not
routed.

Run it with KiCad's own Python (it needs pcbnew), from anywhere:

  /Applications/KiCad/KiCad.app/Contents/Frameworks/Python.framework/Versions/Current/bin/python3 pcb/gen/generate.py

OPENSCAD and KICAD_SYMBOLS / KICAD_FOOTPRINTS can point somewhere else than
the macOS app defaults.
"""

import json
import math
import os
import re
import subprocess
import tempfile
import uuid

import pcbnew

HERE = os.path.dirname(os.path.abspath(__file__))
PCB = os.path.dirname(HERE)
ROOT = os.path.dirname(PCB)
LIB = os.path.join(PCB, "lib")
OPENSCAD = os.environ.get("OPENSCAD", "/Applications/OpenSCAD.app/Contents/MacOS/OpenSCAD")
KICAD_SHARE = "/Applications/KiCad/KiCad.app/Contents/SharedSupport"
KICAD_SYMBOLS = os.environ.get("KICAD_SYMBOLS", os.path.join(KICAD_SHARE, "symbols"))
KICAD_FOOTPRINTS = os.environ.get("KICAD_FOOTPRINTS", os.path.join(KICAD_SHARE, "footprints"))

# where the boards sit on their pages (mm), so nothing has negative coordinates
SENSOR_ORIGIN = (150.0, 100.0)
BASE_ORIGIN = (150.0, 100.0)


def uid():
    return str(uuid.uuid4())


# ---------------------------------------------------------------- case model

def case_geometry():
    """Board outlines (as KiCad-oriented polygons) and positions, from the case."""
    scad = os.path.join(ROOT, "case", "rollino.scad")
    out = {}
    with tempfile.TemporaryDirectory() as tmp:
        for part in ("sensor_pcb", "base_pcb"):
            svg = os.path.join(tmp, part + ".svg")
            res = subprocess.run([OPENSCAD, "-o", svg, "-D", 'part="%s"' % part, scad],
                                 capture_output=True, text=True, check=True)
            out[part] = svg_polygons(open(svg).read())
            m = re.search(r'ECHO: "KICAD (\{.*\})"', res.stderr)
            out["pos"] = json.loads(m.group(1).replace('\\"', '"'))
    return out


def svg_polygons(svg):
    """OpenSCAD's SVG paths as lists of points; its SVG already has y down,
    like KiCad."""
    polys = []
    for d in re.findall(r'<path d="([^"]*)"', svg):
        for sub in re.split(r'[Zz]', d):
            pts = []
            for x, y in re.findall(r'([-\d.e]+),([-\d.e]+)', sub):
                q = (float(x), float(y))
                # OpenSCAD repeats some points: drop zero-length segments
                if not pts or math.hypot(q[0] - pts[-1][0], q[1] - pts[-1][1]) > 1e-3:
                    pts.append(q)
            if len(pts) > 2 and math.hypot(pts[0][0] - pts[-1][0], pts[0][1] - pts[-1][1]) <= 1e-3:
                pts.pop()
            if len(pts) > 2:
                polys.append(pts)
    return polys


# ---------------------------------------------------------------- symbols

def sexpr_block(text, start):
    """The balanced (...) starting at index start."""
    depth = 0
    for i in range(start, len(text)):
        if text[i] == '(':
            depth += 1
        elif text[i] == ')':
            depth -= 1
            if depth == 0:
                return text[start:i + 1]
    raise ValueError("unbalanced")


def library_symbol(lib, name):
    """A symbol from KiCad's libraries, as embedded in a schematic
    ("lib:name"), with a derived symbol flattened onto its parent."""
    text = open(os.path.join(KICAD_SYMBOLS, lib + ".kicad_sym")).read()
    i = text.find('(symbol "%s"' % name)
    block = sexpr_block(text, i)
    ext = re.search(r'\(extends "([^"]+)"\)', block)
    if ext:
        parent = name_of = ext.group(1)
        pblock = sexpr_block(text, text.find('(symbol "%s"' % parent))
        # the child's own properties replace the parent's
        props = {m.group(1): sexpr_block(block, m.start())
                 for m in re.finditer(r'\(property "([^"]+)"', block)}
        for key, prop in props.items():
            pm = re.search(r'\(property "%s"' % re.escape(key), pblock)
            if pm:
                pblock = pblock.replace(sexpr_block(pblock, pm.start()), prop)
        block = pblock.replace('(symbol "%s_' % name_of, '(symbol "%s_' % name)
        block = block.replace('(symbol "%s"' % name_of, '(symbol "%s"' % name, 1)
    return block.replace('(symbol "%s"' % name, '(symbol "%s:%s"' % (lib, name), 1)


def custom_symbol_text(name, ref, value, footprint, description, pins, body, datasheet="~"):
    """A symbol: pins are (number, name, type, x, y, angle)."""
    pin_text = "".join(
        '\n\t\t\t(pin %s line (at %g %g %d) (length 2.54)%s'
        ' (name "%s" (effects (font (size 1.27 1.27))))'
        ' (number "%s" (effects (font (size 1.27 1.27)))))'
        % (typ, x, y, a, "", pname, num) for num, pname, typ, x, y, a in pins)
    (x0, y0), (x1, y1) = body
    return '''(symbol "%s" (pin_names (offset 1.016)) (exclude_from_sim no) (in_bom yes) (on_board yes)
		(property "Reference" "%s" (at %g %g 0) (effects (font (size 1.27 1.27)) (justify left)))
		(property "Value" "%s" (at %g %g 0) (effects (font (size 1.27 1.27)) (justify left)))
		(property "Footprint" "%s" (at 0 0 0) (effects (font (size 1.27 1.27)) hide))
		(property "Datasheet" "%s" (at 0 0 0) (effects (font (size 1.27 1.27)) hide))
		(property "Description" "%s" (at 0 0 0) (effects (font (size 1.27 1.27)) hide))
		(symbol "%s_0_1"
			(rectangle (start %g %g) (end %g %g) (stroke (width 0.254) (type default)) (fill (type background))))
		(symbol "%s_1_1"%s))''' % (
        name, ref, x0, y1 + 1.27, value, x0, y0 - 1.27, footprint, datasheet, description,
        name, x0, y1, x1, y0, name, pin_text)


PMW3610_PINS = [
    # number, name, type, x, y, angle: signals on the left, power on the right
    ("2", "SDIO", "bidirectional", -12.7, 7.62, 0),
    ("3", "SCLK", "input", -12.7, 5.08, 0),
    ("5", "NCS", "input", -12.7, 2.54, 0),
    ("8", "MOTION", "output", -12.7, 0, 0),
    ("7", "NRESET", "input", -12.7, -2.54, 0),
    ("6", "VDDIO", "power_in", -12.7, -7.62, 0),
    ("4", "NC", "no_connect", -12.7, -10.16, 0),
    ("14", "VDD", "power_in", 12.7, 7.62, 180),
    ("9", "VCP", "passive", 12.7, 5.08, 180),
    ("12", "CP", "passive", 12.7, 2.54, 180),
    ("13", "CN", "passive", 12.7, 0, 180),
    ("1", "+VCSEL", "passive", 12.7, -2.54, 180),
    ("10", "PASS_T", "passive", 12.7, -5.08, 180),
    ("15", "XYLASER", "passive", 12.7, -7.62, 180),
    ("16", "-VCSEL", "passive", 12.7, -10.16, 180),
    ("11", "GND", "power_in", 0, -15.24, 90),
]
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

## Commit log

2026-09-27 Add parametric case model for two-sensor low-profile trackball
    OpenSCAD model with a 55 mm ball floating 1 mm above the table, two
    PMW3610 sensors placed below the equator with orthogonal lines of sight,
    and a slanted nice!nano + 402030 LiPo pod. Also adds PMW3389 footprint
    and 3D models, and updates the readme for the PMW3610/ZMK direction.
    [pmw_3389-T3QU.stl, pmw_3389-T3QU.stp, rollino.scad]
2026-10-05 Rounded bumps
    [rollino.scad]
2026-10-07 Mount sensor PCBs from the ball side with one screw, close the pod backs
    The PCB + lens now drop into a PCB-shaped pocket open towards the ball and
    are held by a single M2 self-tapper through one ear into a boss behind it;
    a closed cavity behind the PCB clears the chip and joins the wire channel.
    [rollino.scad]
2026-10-07 Front pod: flat squashed dome for a XIAO nRF52840 + 602020, screw-on lid; exploded view
    The XIAO lies upside down on a lid screwed on from underneath, battery on
    top, USB-C pointing forward through a plug recess. The pod's outer is an
    oblate spheroid whose height follows from its width (elec_dome_d).
    Add part="exploded" and a render of it, linked from the readme.
    [rollino.scad]
2026-10-07 Push the front dome 3.5 mm back towards the ball
    The cavity stays put; the dome's height is now worked out from its front
    corners, so it grows from ~19 to ~23 mm.
    [rollino.scad]
2026-10-07 Use Seeed's XIAO nRF52840 3D model and a parametric 602020 pouch cell
    The XIAO STL is converted from Seeed's (Sense) STEP model; its real board
    thickness and USB-C overhang replace the assumed values. The battery is
    drawn in OpenSCAD (pouch, taped protection board, leads) at the larger
    listed size, 22 x 20 x 6.5, with room behind it for the leads. Section
    views cut the imported (not closed) mesh in preview instead of CGAL.
    [rollino.scad, xiao-nrf52840.stl]
2026-10-07 Exploded view: real XIAO and battery, lid screws right under their holes
    Drop the sensor screws, which read as floating in front of the lenses.
    [rollino.scad]
2026-10-07 Re-render all previews for the current design
    Section views draw the XIAO as plain boxes, which CGAL can cut, instead
    of the imported mesh (not closed), whose preview cut bled over the whole
    cut plane.
    [rollino.scad]
2026-10-08 Base PCB under the case, screw-on cover, FPC ribbons to the sensors
    The XIAO is soldered upside down onto a base PCB (parts through a cutout,
    into a pocket in the cover) that sits in a groove in the underside and
    reaches round under both sensors. Each sensor board gets an FPC connector
    beside its chip (and loses its second ear); a ribbon runs down a slot to a
    connector on the base PCB. A cover over the whole underside hides the PCB;
    the same countersunk screws hold both. Replaces the front lid and the
    wire channels. part="base_pcb" exports the outline for the PCB's edge cuts.
    [rollino.scad]
2026-10-08 ZMK firmware: standalone mouse, two sensors fused into pointer + twist scroll
    Shield for the XIAO nRF52840 with both PMW3610s on one SPI bus (Zephyr's
    driver) and three optional buttons; a small module (rollino,ball-fusion)
    solves the ball's rotation from the two sensors' readings and reports
    pointer motion and, for twist, scrolling. Built by GitHub Actions.
2026-10-08 KiCad projects for the sensor and base boards; FPC connectors at board ends
    pcb/gen/generate.py writes both projects (schematic + placed, unrouted
    board) from the case model's outlines and positions. Sensor board: PMW3610
    circuit after badjeff/pmw3610-pcb (CERN-OHL-P) with a 1 uA TPS7A0518 LDO and
    an FH12-6S connector at its up-slope end, so the ribbon runs over the chip
    and straight down; both sensors now use the same board. The base PCB's band
    ends straight just past its connectors, no lobes.
    [rollino-base.kicad_pcb, rollino-base.kicad_sch, rollino-sensor.kicad_pcb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]
2026-10-08 Route both PCBs, copper logo, 3D renders of the boards
    pcb/gen/route.py has Freerouting route every net (edge and logo keep-outs,
    retrying strategies until nothing is left unconnected) and pours GND;
    pcb/gen/render_pcbs.sh renders both boards in Blender from KiCad's VRML,
    with generated models for the upside-down XIAO and the PMW3610 + lens. The
    ROLLINO logo is now bare copper on the back of the band instead of
    silkscreen cut by the XIAO's cutout. Connector mounting tabs go to GND;
    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
    [rollino-base.kicad_pcb, rollino-base.kicad_sch, rollino-sensor.kicad_pcb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]
2026-10-10 Sensor FPC mouth at the board edge, roomier ribbon channel, clean DRC
    The sensor board's FH12 now faces off its up-slope edge, so the ribbon can
    be pushed in and latched before the board goes into its pod; the pod has
    room for the ribbon's U-turn back over the connector. The ribbon's channel
    down through the pod is wider and deeper: part="fpc_check" sweeps a 1.5 mm
    thick stand-in along its path and must come out empty, so the free end can
    be fed through from either end. Ribbons are 40 mm.
    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
    [rollino-base.kicad_pcb, rollino-base.kicad_sch, rollino-sensor.kicad_pcb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]
2026-10-10 Shorter base band for a stock 50 mm FFC, parts list, FPC pin order fix
    The base board's band now ends at about 110 degrees, with the FPC
    connectors lying along it; each ribbon creases flat under its sensor pod
    and runs along a channel in the case's underside, held by the cover.
    The model solves the crease position from fpc_len = 50 (type B cable).
    Connector pins are numbered from the ribbon's path so each signal meets
    itself (the flipped sensor connector had reversed them).
    Adds parts.md, the parts to order.
    [rollino-base.kicad_pcb, rollino-base.kicad_sch, rollino-sensor.kicad_pcb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]
2026-10-11 Route the base board again, clear the antenna, sensor decoupling by the pins
    The base board had come out with nothing routed to its FPC connectors:
    Freerouting can't start a track from their pads at this angle. generate.py
    now lays a stub out of each pad and route.py has Freerouting join those;
    route.py only saves a board that is whole and that KiCad's DRC has nothing
    to report on, trying its other strategies otherwise.
    Base board: no pour by the XIAO's antenna (the strip between the notch and
    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
2026-11-14 Ring, rim and front pod as one swept surface
    The ring's section is swept on round the front, easing down to the rim
    and swelling into a flat, low front pod through a filleted waist, so
    there is no step or valley where the ridge meets the base. The base PCB
    outline no longer depends on the ring and is unchanged.

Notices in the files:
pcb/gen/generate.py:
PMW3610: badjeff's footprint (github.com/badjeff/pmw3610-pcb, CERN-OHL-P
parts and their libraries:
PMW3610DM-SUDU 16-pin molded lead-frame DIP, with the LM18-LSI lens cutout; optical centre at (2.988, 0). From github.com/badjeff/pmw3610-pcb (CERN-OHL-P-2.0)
